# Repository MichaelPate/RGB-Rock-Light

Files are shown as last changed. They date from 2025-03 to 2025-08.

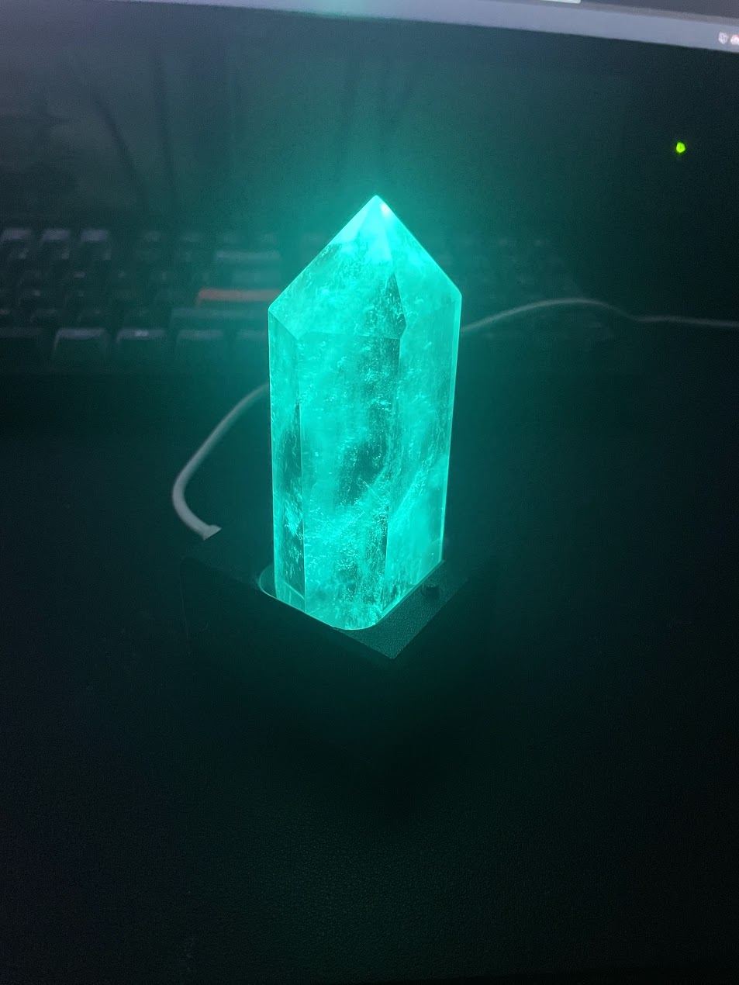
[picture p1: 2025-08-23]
3D Design/IMG_1655.jpg

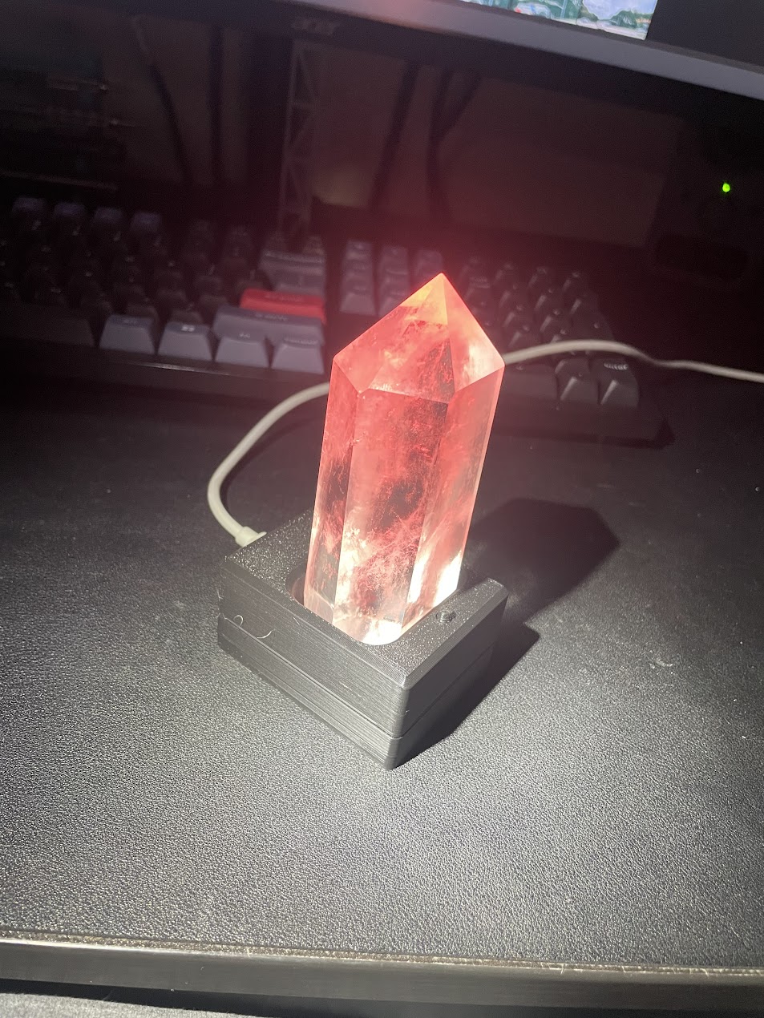
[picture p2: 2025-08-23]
3D Design/IMG_1661.jpg

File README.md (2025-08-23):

# RGB Rock Light
 RGB LED decoration for a big crystal. This code is designed for an ATTiny85. Its meant to be powered over USB and just sits around as a decoration.
 This is currently v2 of the design. It uses the built in EEPROM library, the Adafruit NeoPixel library, and the ATTiny board manager URL from:
 https://raw.githubusercontent.com/damellis/attiny/ide-1.6.x-boards-manager/package_damellis_attiny_index.json

To program the board more easily, I designed a programmer shield for an Arduino Uno that lets me use a programming cable on JST PH headers.
See the link below to that repo. https://github.com/MichaelPate/Arduino-ISP-PROgrammer-Shield/tree/main

I will eventually get around to designing an enclosure for this. When that happens, ill put it on thingiverse and add the link here!
https://www.thingiverse.com/thing:7125638





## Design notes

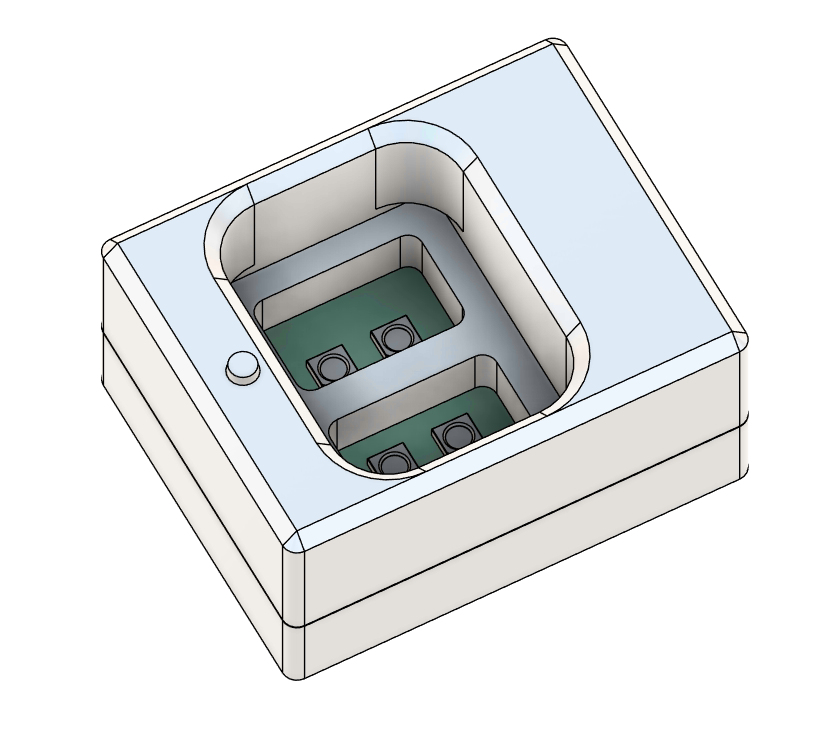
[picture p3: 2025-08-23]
3D Design/Screenshot_20250822_210329.png

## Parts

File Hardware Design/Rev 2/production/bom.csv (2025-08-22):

Designator | Footprint | Quantity | Value | LCSC Part #
C1, C2 | 0603 | 2 | 1u
D1, D2, D3, D4 | LED_WS2812B_PLCC4_5.0x5.0mm_P3.2mm | 4 | WS2812B
J1 | USB_C_Receptacle_G-Switch_GT-USB-7010ASV | 1 | USB_C_Receptacle_USB2.0_16P
J2 | JST_PH_B6B-PH-K_1x06_P2.00mm_Vertical | 1 | ISP
JP1 | SolderJumper-2_P1.3mm_Open_TrianglePad1.0x1.5mm | 1 | Jumper_2_Small_Open
R1, R2 | 0402 | 2 | 5k1
R3 | 0402 | 1 | 10k
SW1 | SW_SPST_PTS647_Sx38 | 1 | USER
SW2 | SW_SPST_PTS647_Sx38 | 1 | RESET
TP1 | TestPoint_Pad_D1.5mm | 1 | SIG
TP2 | TestPoint_Pad_D1.5mm | 1 | +5V
TP3 | TestPoint_Pad_D1.5mm | 1 | GND
U1 | SOIC-8_5.3x5.3mm_P1.27mm | 1 | ATtiny85-10SU

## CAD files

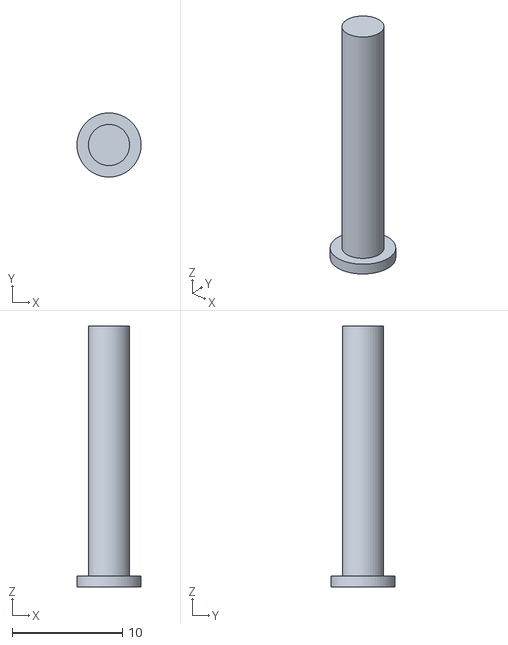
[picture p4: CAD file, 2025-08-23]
3D Design/Button.stl
5.83 x 5.83 x 23.7

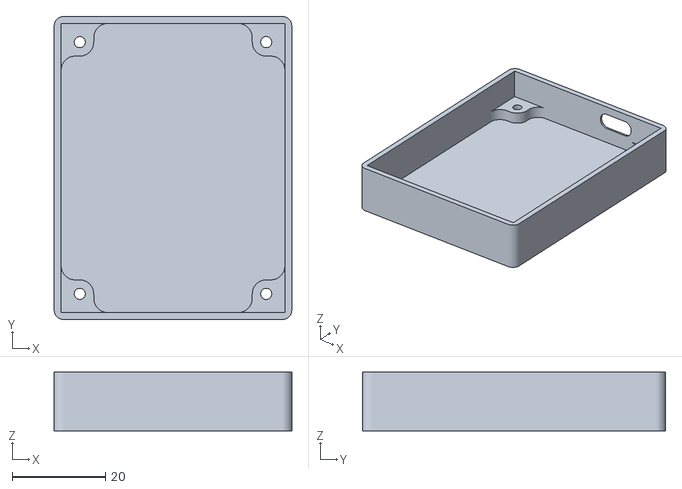
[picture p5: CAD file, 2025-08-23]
3D Design/bottom chassis.stl
51.0 x 65.0 x 12.6

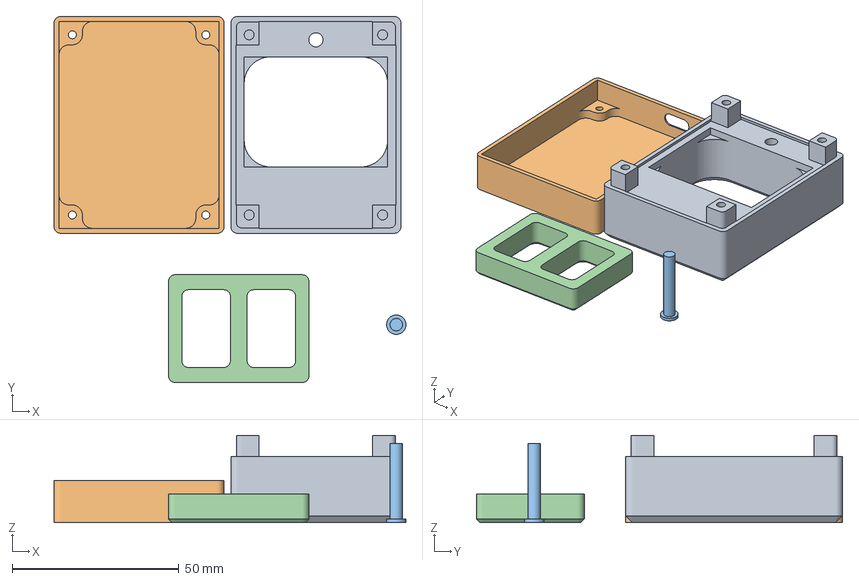
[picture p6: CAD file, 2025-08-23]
3D Design/enclosure.3mf
105.5 x 109.7 x 26.1 mm
top chassis.stl
bottom chassis.stl
Button.stl
spacer block.stl

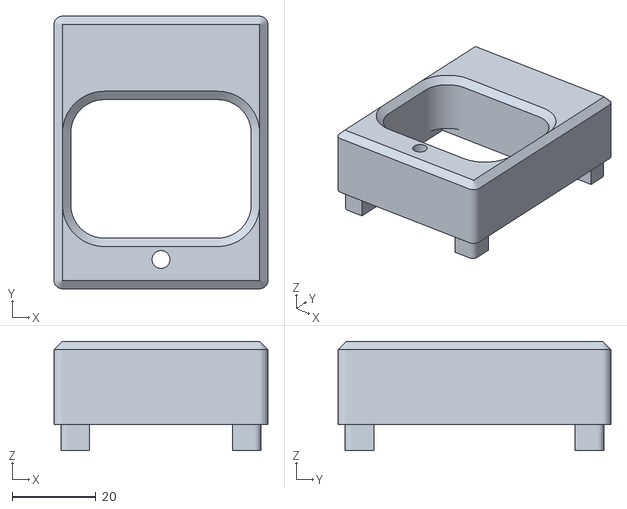
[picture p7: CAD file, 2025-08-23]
3D Design/top chassis.stl
51.0 x 65.0 x 26.1

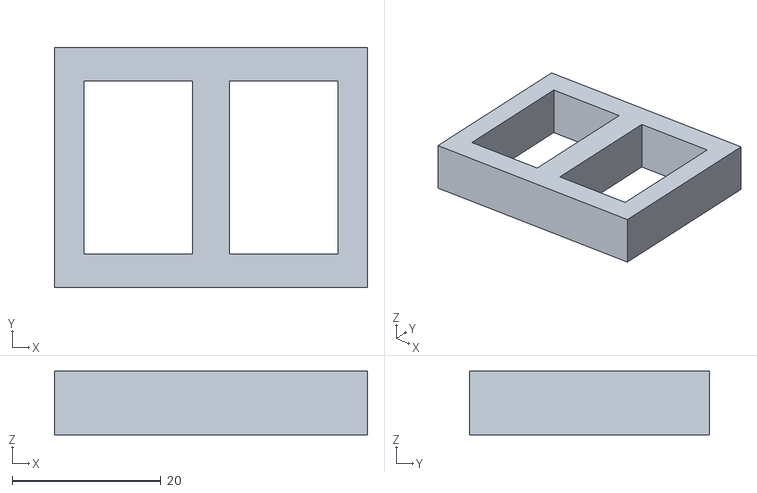
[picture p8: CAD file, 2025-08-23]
3D Design/spacer block.stl
42.1 x 32.3 x 8.60

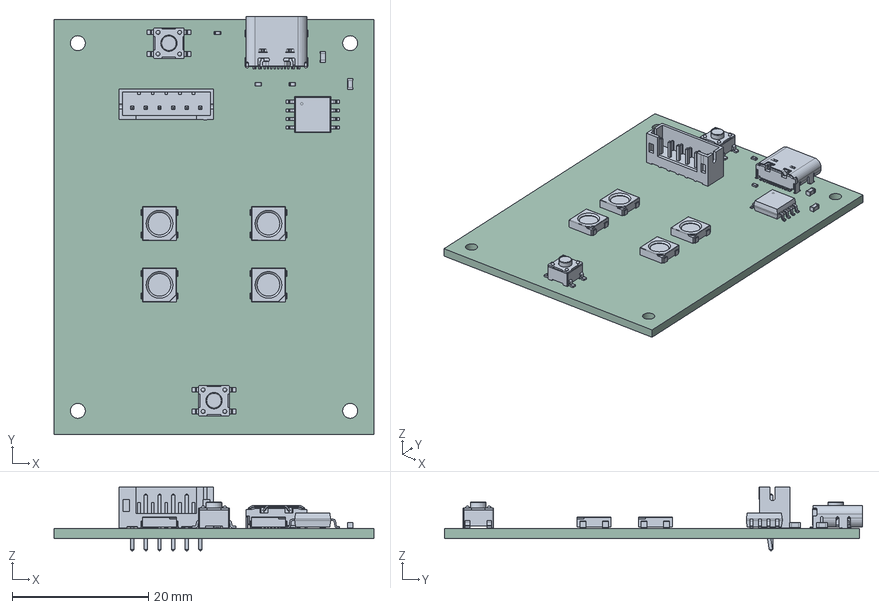
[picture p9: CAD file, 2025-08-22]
3D Design/RockLight_PCB_V2.step
47.0 x 61.5 x 9.40 mm
SOIC-8_5.3x5.3mm_P1.27mm
SW_SPST_PTS647Sx38 x 2
R_0402_1005Metric x 3
LED_WS2812B_PLCC4_5.0x5.0mm_P3.2mm x 4
JST_PH_B6B-PH-K_1x06_P2.00mm_Vertical
USB4105GFA_USB4105GFA
C_0603_1608Metric x 2
RockLight_PCB

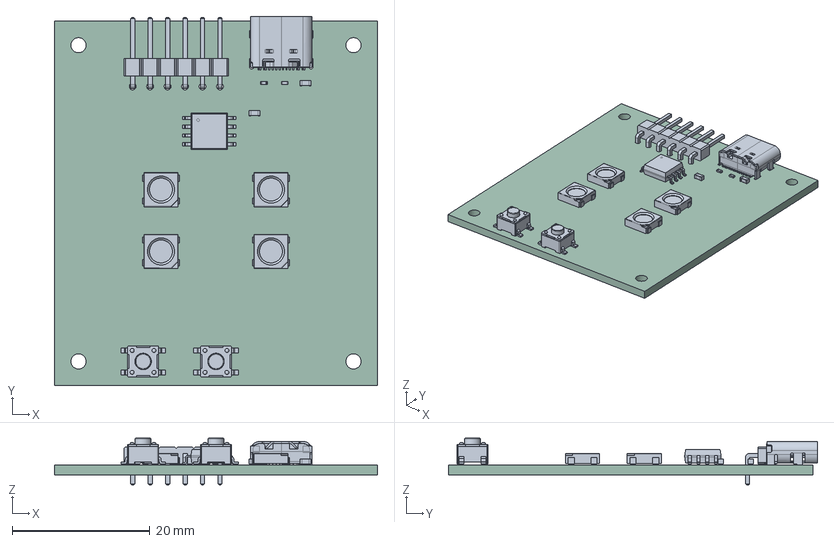
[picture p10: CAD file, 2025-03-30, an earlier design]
Hardware Design/Rev 1/RockLight.step
47.0 x 53.7 x 6.80 mm
LED_WS2812B_PLCC4_5.0x5.0mm_P3.2mm x 4
SW_SPST_PTS647Sx38 x 2
R_0402_1005Metric x 2
PinHeader_1x06_P2.54mm_Horizontal
C_0603_1608Metric x 2
USB_C_Receptacle_GCT_USB4105-xx-A_16P_TopMnt_Horizontal
SOIC-8_5.3x5.3mm_P1.27mm
RockLight_PCB

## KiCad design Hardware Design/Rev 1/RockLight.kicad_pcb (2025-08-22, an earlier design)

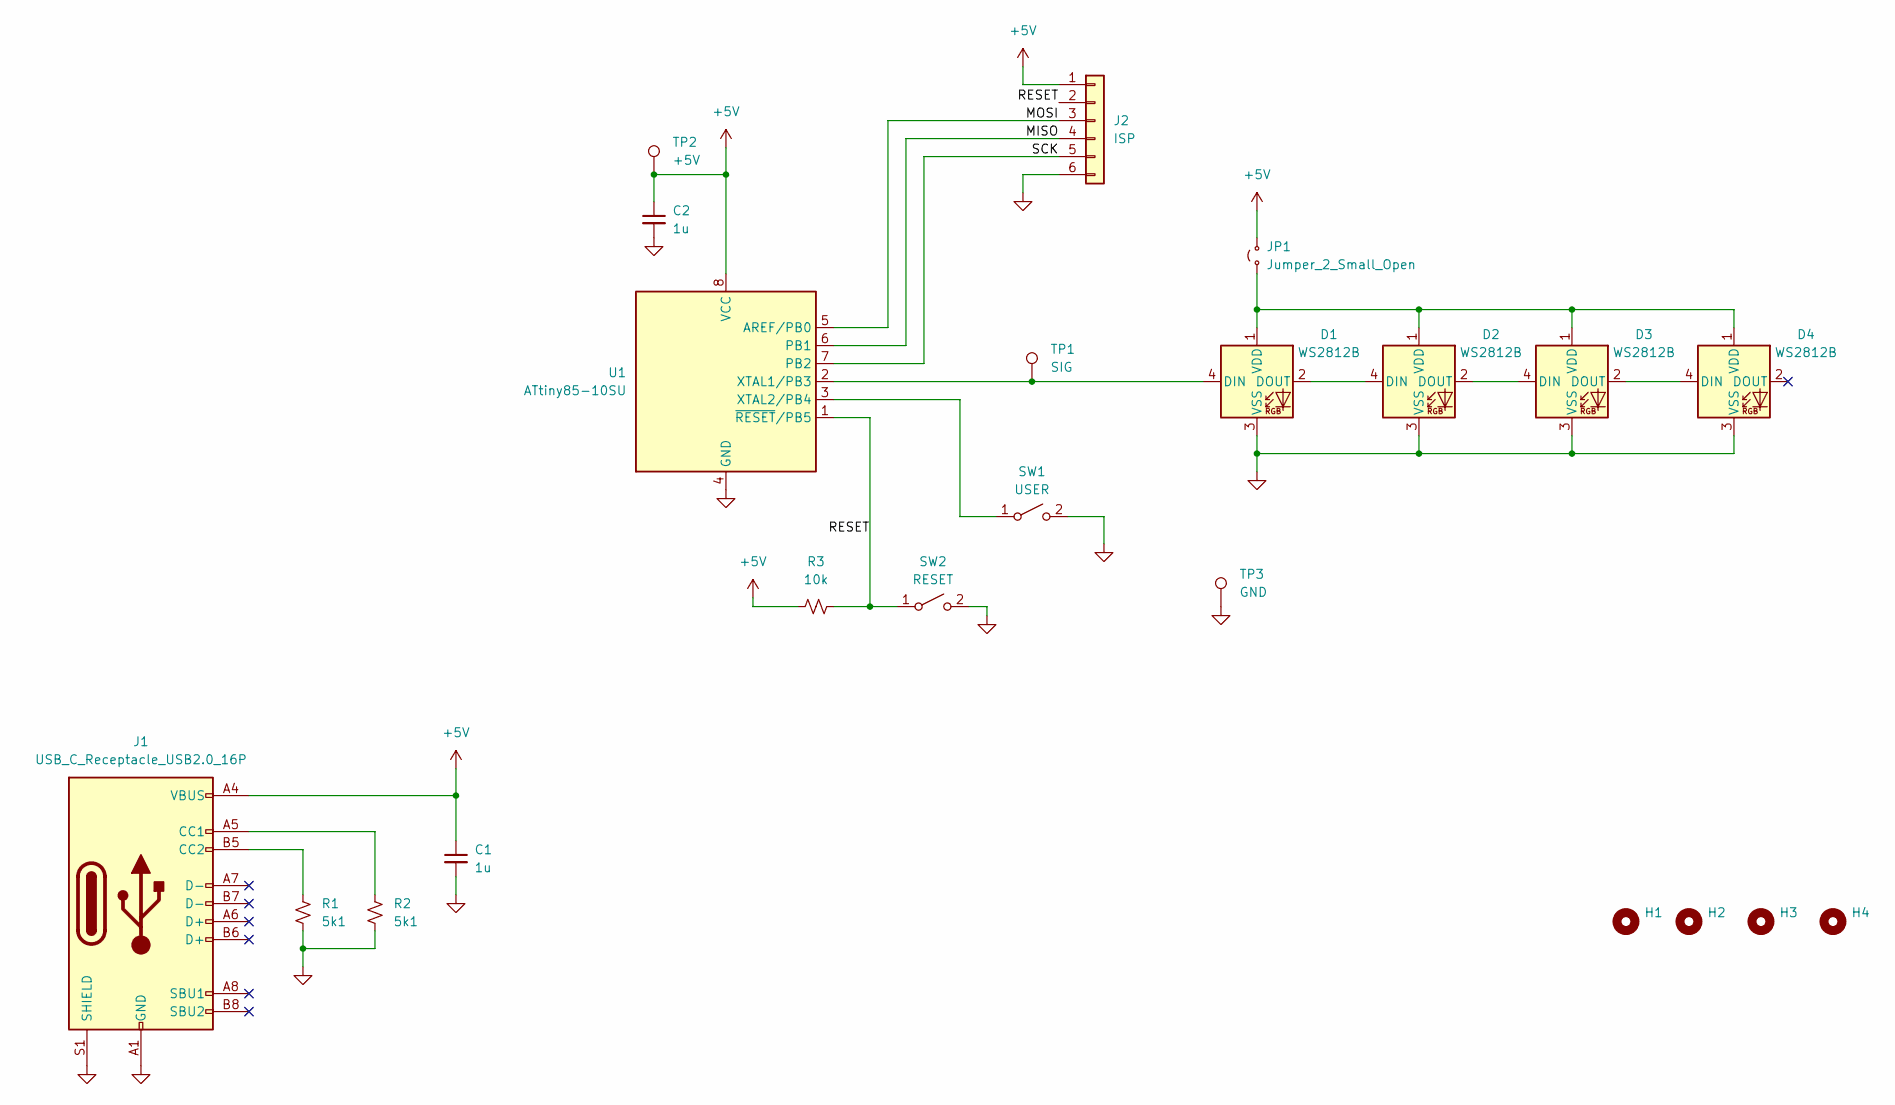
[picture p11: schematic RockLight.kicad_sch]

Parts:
C1, C2: 1u; C_0603_1608Metric
D1, D2, D3, D4: WS2812B; LED_WS2812B_PLCC4_5.0x5.0mm_P3.2mm
H1, H2, H3, H4: MountingHole; MountingHole_2.2mm_M2
J1: USB_C_Receptacle_USB2.0_16P; USB_C_Receptacle_G-Switch_GT-USB-7010ASV
J2: ISP; JST_PH_B6B-PH-K_1x06_P2.00mm_Vertical
JP1: Jumper_2_Small_Open; SolderJumper-2_P1.3mm_Open_TrianglePad1.0x1.5mm
R1, R2: 5k1; R_0402_1005Metric
R3: 10k; R_0402_1005Metric
SW1: USER; SW_SPST_PTS647_Sx38
SW2: RESET; SW_SPST_PTS647_Sx38
TP1: SIG; TestPoint_Pad_D1.5mm
TP2: +5V; TestPoint_Pad_D1.5mm
TP3: GND; TestPoint_Pad_D1.5mm
U1: ATtiny85-10SU; SOIC-8_5.3x5.3mm_P1.27mm

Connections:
+5V: C1.1, C2.1, J1.A4 (VBUS), J1.A9 (VBUS), J1.B4 (VBUS), J1.B9 (VBUS), J2.1, JP1.2 (B), R3.1, TP2.1, U1.8 (VCC)
/MISO: J2.4, U1.6 (PB1)
/MOSI: J2.3, U1.5 (AREF/PB0)
/RESET: J2.2, R3.2, SW2.1 (A), U1.1 (~RESET/PB5)
/SCK: J2.5, U1.7 (PB2)
GND: C1.2, C2.2, D1.3 (VSS), D2.3 (VSS), D3.3 (VSS), D4.3 (VSS), J1.A1 (GND), J1.A12 (GND), J1.B1 (GND), J1.B12 (GND), J1.S1 (SHIELD), J2.6, R1.1, R2.1, SW1.2 (B), SW2.2 (B), TP3.1, U1.4 (GND)
unnamed: D1.4 (DIN), TP1.1, U1.2 (XTAL1/PB3)
unnamed: D1.2 (DOUT), D2.4 (DIN)
unnamed: D1.1 (VDD), D2.1 (VDD), D3.1 (VDD), D4.1 (VDD), JP1.1 (A)
unnamed: D2.2 (DOUT), D3.4 (DIN)
unnamed: D3.2 (DOUT), D4.4 (DIN)
unnamed: J1.A5 (CC1), R2.2
unnamed: J1.B5 (CC2), R1.2
unnamed: SW1.1 (A), U1.3 (XTAL2/PB4)

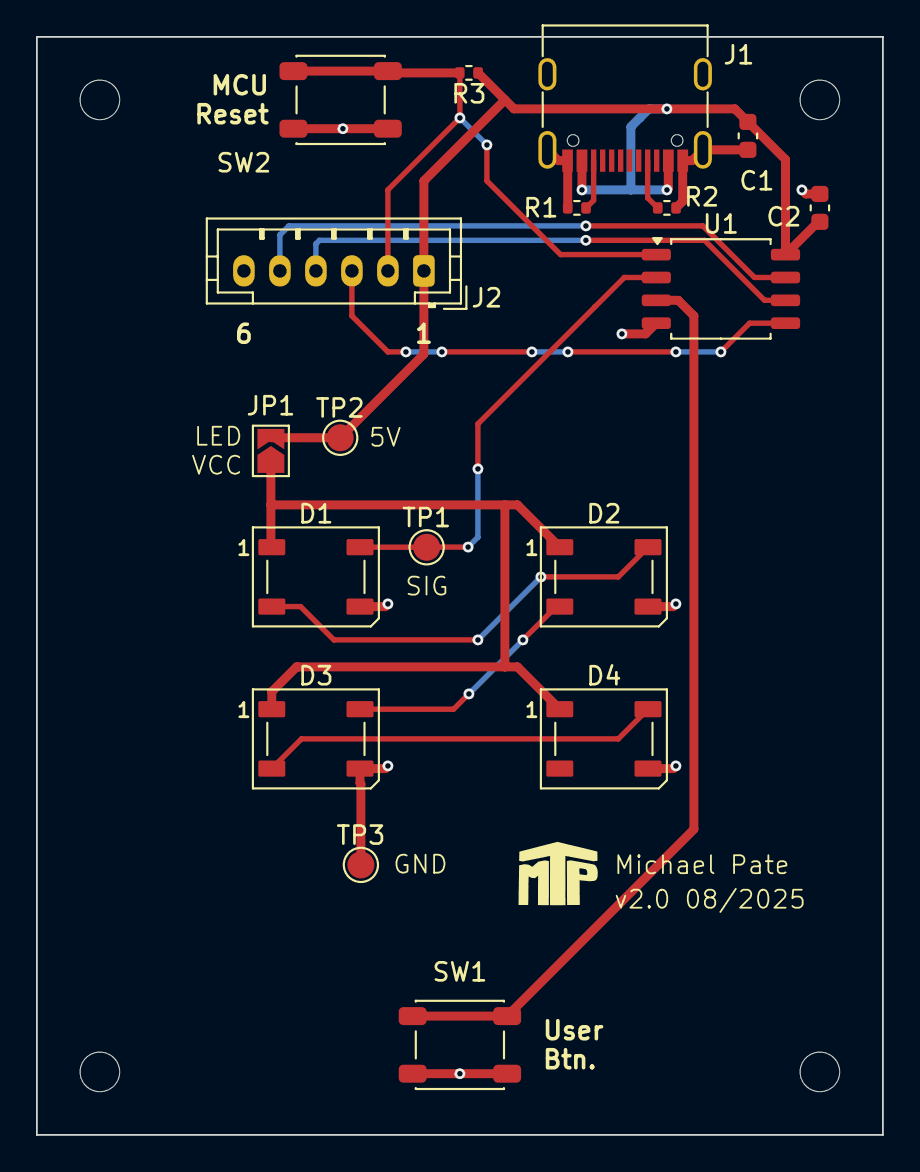
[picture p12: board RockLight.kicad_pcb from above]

Board: 2 copper layers, 47.0 x 61.0 mm, 22 parts (0 on the bottom side), 14 nets.

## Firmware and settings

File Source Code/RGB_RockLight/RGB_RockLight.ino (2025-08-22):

/**
 * Author: Michael Pate
 * Version: 2.0
 * Date: 8-21-2025
 */

#include <EEPROM.h>
#include <Adafruit_NeoPixel.h>

// This was included in the Adafruit example sketch
#ifdef __AVR__
  #include <avr/power.h>
#endif

#define LED_DATA 3
#define USR_BTN 4

// 4x LEDs, 800kHz GRB bitstream
Adafruit_NeoPixel strip = Adafruit_NeoPixel(4, LED_DATA, NEO_GRB + NEO_KHZ800);

// EEPROM addresses to hold data for brightness and the current mode
#define MODE_ADDR 100
#define BRIGHT_ADDR 150 // stored as an index in brightOptions (one-indexed)
byte brightOptions[6] = {0, 25, 50, 100, 150, 200};
// These values will be saved every time they are changed, and loaded on startup
byte mode, brightness_i;
#define DEFAULT_MODE 0
#define DEFAULT_BRIGHT_I 3 // brightness of 50 for index 2

bool buttonState = HIGH;
bool lastButtonState = HIGH;
unsigned long pressStartTime = 0;
bool longPressHandled = false;
#define HOLD_TIME 600

double rainbowColorPosition = 0.0;
unsigned long lastSnapMillis = 0; // last time the color snapped in mode 2

void setup() {
  pinMode(USR_BTN, INPUT_PULLUP);
  pinMode(LED_DATA, OUTPUT);

  // Check if the EEPROM has been written, as in nonzero
  byte testMode = EEPROM.read(MODE_ADDR);
  if (testMode != 255)
  {
    mode = testMode;
  }
  else
  {
    mode = DEFAULT_MODE;
  }

  byte testBright_i = EEPROM.read(BRIGHT_ADDR);
  if (testBright_i != 255)
  {
    brightness_i = testBright_i;
  }
  else
  {
    brightness_i = DEFAULT_BRIGHT_I;
  }

  strip.begin();
  strip.setBrightness(brightOptions[brightness_i]);
  strip.show(); // Initialize all pixels to 'off'

  // for testing
  for (int i=0; i < strip.numPixels(); i++)
  {
    strip.setPixelColor(i, strip.Color(255,0,0));
    strip.show();
  }
}

void fillRed(int bright)
{
  strip.setBrightness(bright);
  for (int i=0; i < strip.numPixels(); i++)
  {
    strip.setPixelColor(i, strip.Color(255,0,0));
    strip.show();
  }
}

void loop() {
  // Handle button presses, holds, and such
  buttonState = digitalRead(USR_BTN);

  // Detect right when the button is pressed
  if (buttonState == LOW && lastButtonState == HIGH)
  {
    pressStartTime = millis();
    longPressHandled = false;
  }

  // Check if the button is still being held
  if (buttonState == LOW && !longPressHandled)
  {
    if (millis() - pressStartTime >= HOLD_TIME)
    {
      // long press action - change brightness and save to EEPROM
      if (++brightness_i > 5)
      {
        brightness_i = 0;
      }
      EEPROM.write(BRIGHT_ADDR, brightness_i);
      strip.setBrightness(brightOptions[brightness_i]);
      
      longPressHandled = true;
    }
  }

  // Button just released
  if (buttonState == HIGH && lastButtonState == LOW)
  {
    if (!longPressHandled)
    {
      // short press action - change mode and save to EEPROM
      if (++mode > 10)
      {
        mode = 0;
      }
      rainbowColorPosition = 0.0;
      EEPROM.write(MODE_ADDR, mode);
    }
  }
  lastButtonState = buttonState;

  uint32_t colorTarget;
  switch(mode)
  {
    case 0:
    {
      // rainbow mode, but kind of like a wheel
      if (rainbowColorPosition > 1024.0) rainbowColorPosition = 0.0;
      else rainbowColorPosition += 0.19;
      for(int i=0; i<strip.numPixels(); i++)
      {
        strip.setPixelColor(i, colorFrom1024(int(rainbowColorPosition + i * 200), strip));
      }
      strip.show();
      delay(1);
      break;
    }
    case 1:
    {
      // rainbow mode, slowly cycle through the colors
      if (rainbowColorPosition > 1024.0) rainbowColorPosition = 0.0;
      else rainbowColorPosition += 0.1;
      for(int i=0; i<strip.numPixels(); i++) 
      {
        strip.setPixelColor(i, colorFrom1024(int(rainbowColorPosition), strip));
      }
      strip.show();
      delay(1);
      break;
    }
    case 2:
    {
      // rainbow mode, slowly cycle through the colors a little faster
      if (rainbowColorPosition > 1024.0) rainbowColorPosition = 0.0;
      else rainbowColorPosition += 0.33;
      for(int i=0; i<strip.numPixels(); i++) 
      {
        strip.setPixelColor(i, colorFrom1024(int(rainbowColorPosition), strip));
      }
      strip.show();
      delay(1);
      break;
    }
    case 3:
    {
      // Still a rainbow but just snapping through the 6 primary colors
      if (rainbowColorPosition > 853.0) rainbowColorPosition = 0.0; // 853 because thats 1024-170, so red doesnt show twice
      unsigned long now_millis = millis();
      if (now_millis - lastSnapMillis > 2000)
      {
        rainbowColorPosition += 170;  // 1024 / 6 = 170
        lastSnapMillis = now_millis;
      }
      for(int i=0; i<strip.numPixels(); i++)
      {
        strip.setPixelColor(i, colorFrom1024(int(rainbowColorPosition), strip));
      }
      strip.show();
      delay(1);
      break;
    }
    case 4:
    {
      // Show white static
      strip.fill(strip.Color(255,255,255));
      strip.show();
      delay(1);
      break;
    }
    case 5:
    {
      // Show red static
      strip.fill(strip.Color(255,0,0));
      strip.show();
      delay(1);
      break;
    }
    case 6:
    {
      // Show green static
      strip.fill(strip.Color(0,255,0));
      strip.show();
      delay(1);
      break;
    }
    case 7:
    {
      // Show blue static
      strip.fill(strip.Color(0,0,255));
      strip.show();
      delay(1);
      break;
    }
    case 8:
    {
      // Show yellow static
      strip.fill(strip.Color(255,255,0));
      strip.show();
      delay(1);
      break;
    }
    case 9:
    {
      // Show cyan static
      strip.fill(strip.Color(0,255,255));
      strip.show();
      delay(1);
      break;
    }
    case 10:
    {
      // Show purple static
      strip.fill(strip.Color(255,0,255));
      strip.show();
      delay(1);
      break;
    }
    default:
    {
      // Default to just showing white
      strip.fill(strip.Color(255,255,255));
      strip.show();
      delay(1);
      break;
    }
  }
}

// Map a 0–1023 input into a NeoPixel color
uint32_t colorFrom1024(uint16_t pos, Adafruit_NeoPixel &strip) {
  // constrain to 0–1023
  pos = pos & 0x3FF; // wrap if needed

  // Scale 0–1023 into 0–767 (3 * 256)
  uint16_t scaled = (pos * 768L) / 1024;

  uint8_t r, g, b;

  if (scaled < 256) {
    // Red -> Green
    r = 255 - scaled;
    g = scaled;
    b = 0;
  } else if (scaled < 512) {
    // Green -> Blue
    scaled -= 256;
    r = 0;
    g = 255 - scaled;
    b = scaled;
  } else {
    // Blue -> Red
    scaled -= 512;
    r = scaled;
    g = 0;
    b = 255 - scaled;
  }

  // Use Adafruit's helper
  return strip.Color(r, g, b);
}

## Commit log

2025-03-29 Make circuit and PCB
    [RockLight.kicad_pcb, RockLight.kicad_sch, bom.csv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]
2025-03-30 board files produced, PCB ordered
    [RockLight.kicad_pcb]
2025-03-30 generate 3d model
    [RockLight.step]
2025-08-22 Add project files
    [RockLight.kicad_pcb, RockLight.kicad_sch, RockLight.step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]
2025-08-22 move files around to be neater
    [RockLight.kicad_pcb, RockLight.kicad_sch, RockLight_OLD.kicad_pcb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]
2025-08-22 Add 3D file for v2 PCB
    [RockLight_PCB_V2.step]
2025-08-23 add more design files
    [Button.stl, RockLight.kicad_pcb, RockLight.kicad_sch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]
2025-08-23 clean up structure
    [RockLight.kicad_pcb, RockLight.kicad_sch, RockLight.step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]
